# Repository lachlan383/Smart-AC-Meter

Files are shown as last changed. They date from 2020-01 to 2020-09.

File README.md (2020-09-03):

# Smart-AC-Meter
Project repo for the hardware and software design of a household AC power monitor with smartphone interface.

***Update 2020-08-24:***
PCBs arrived a few weeks ago and have now been fully assembled and successfully tested. Soldering of the 0.5mm QFN was extremely tricky and only successful (initially) on one of the three boards. For a full hardware build and verification writeup please see the [Hardware Review Document](https://github.com/lachlan383/Smart-AC-Meter/raw/master/Documentation/Hardware%20Review.docx)*(TBD)*.

<p align="center">
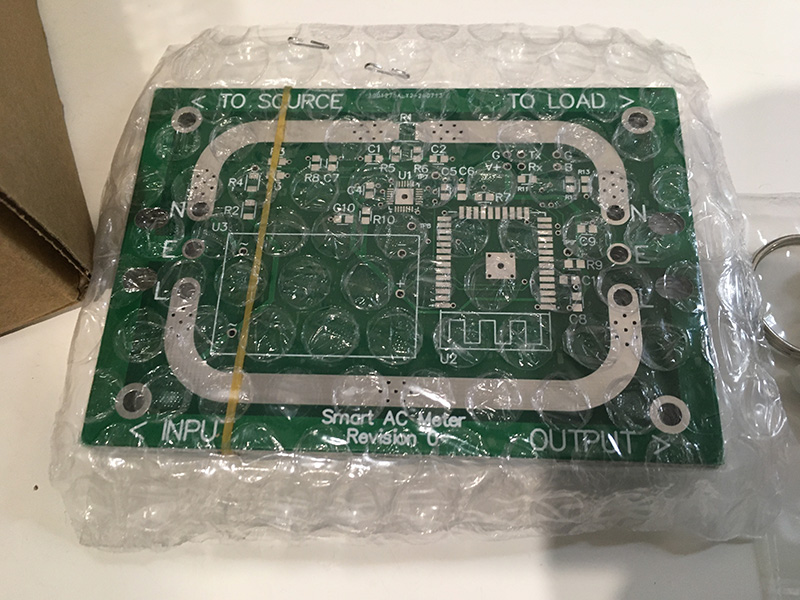
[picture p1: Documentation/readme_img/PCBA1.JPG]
    
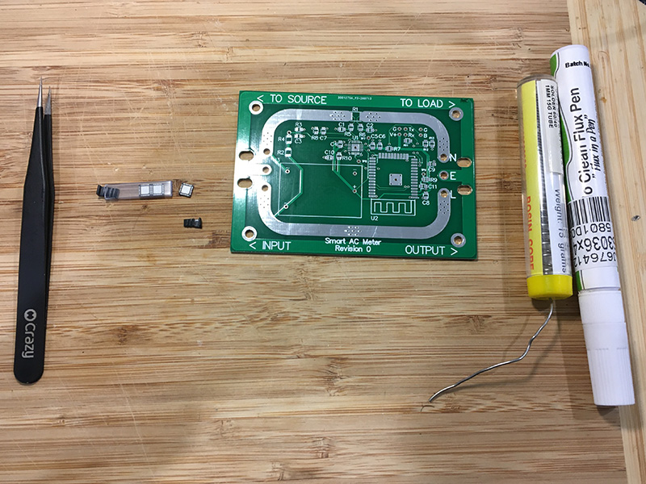
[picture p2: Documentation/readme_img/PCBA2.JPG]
    
  <br/>
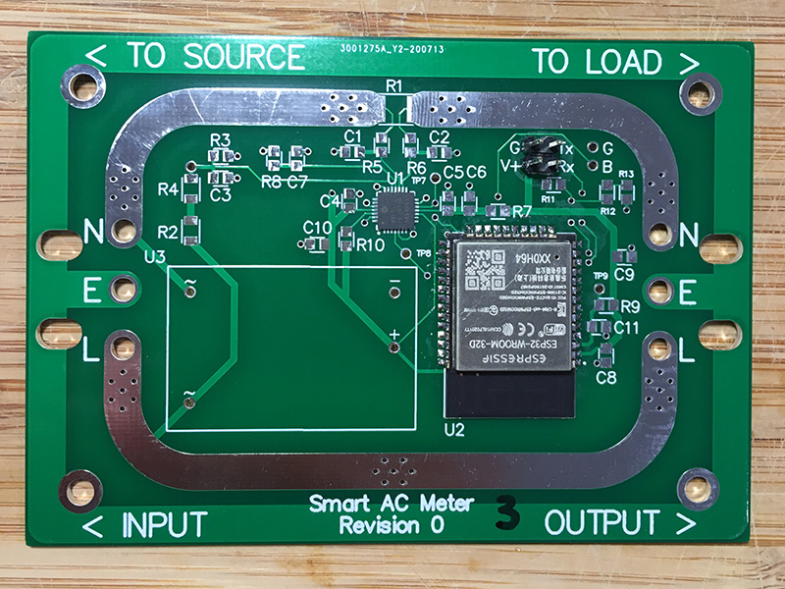
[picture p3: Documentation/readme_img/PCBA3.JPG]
    
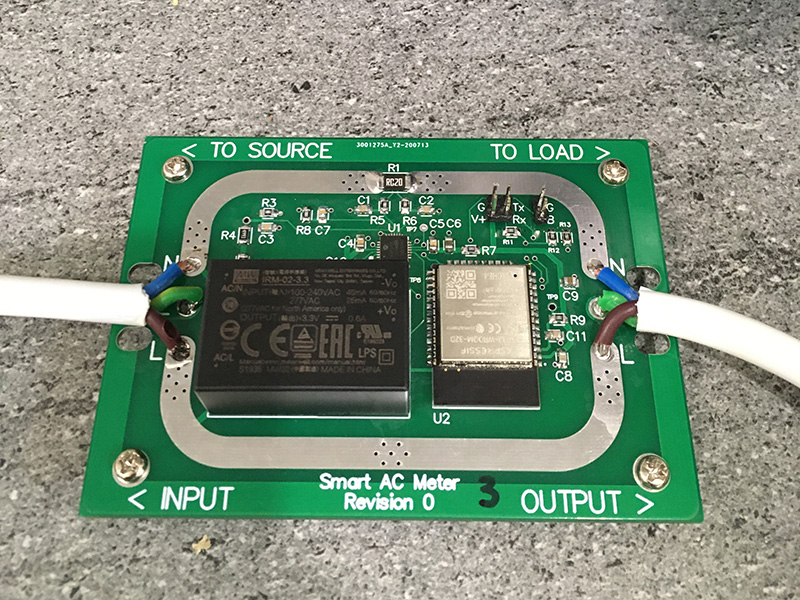
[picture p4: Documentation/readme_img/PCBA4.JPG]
    
  <br/>
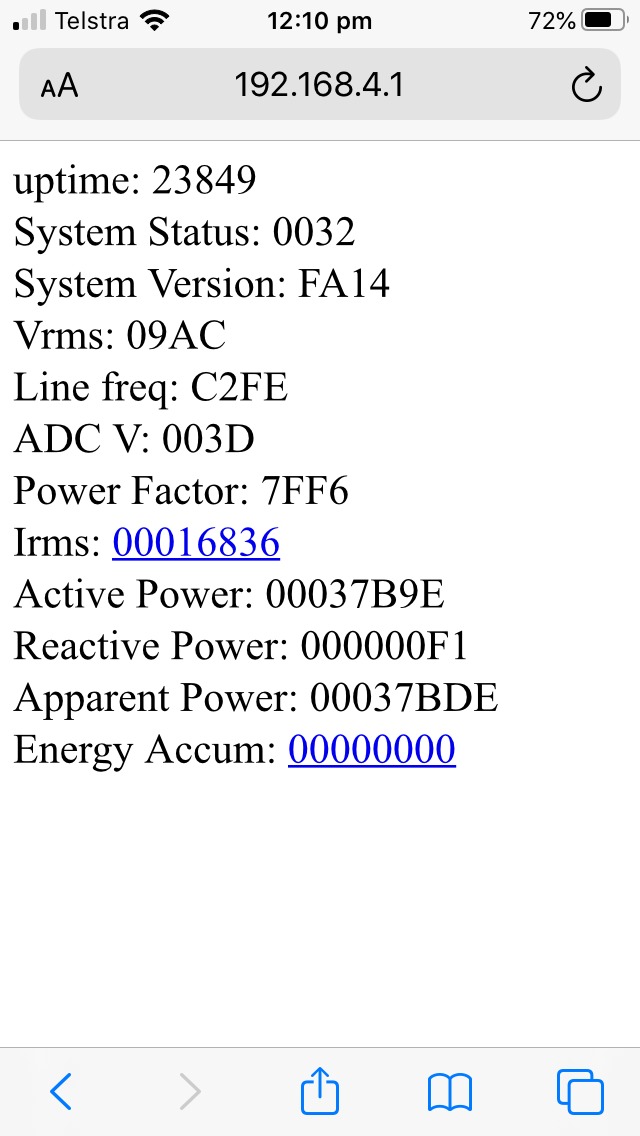
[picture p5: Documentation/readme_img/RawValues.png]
    
          
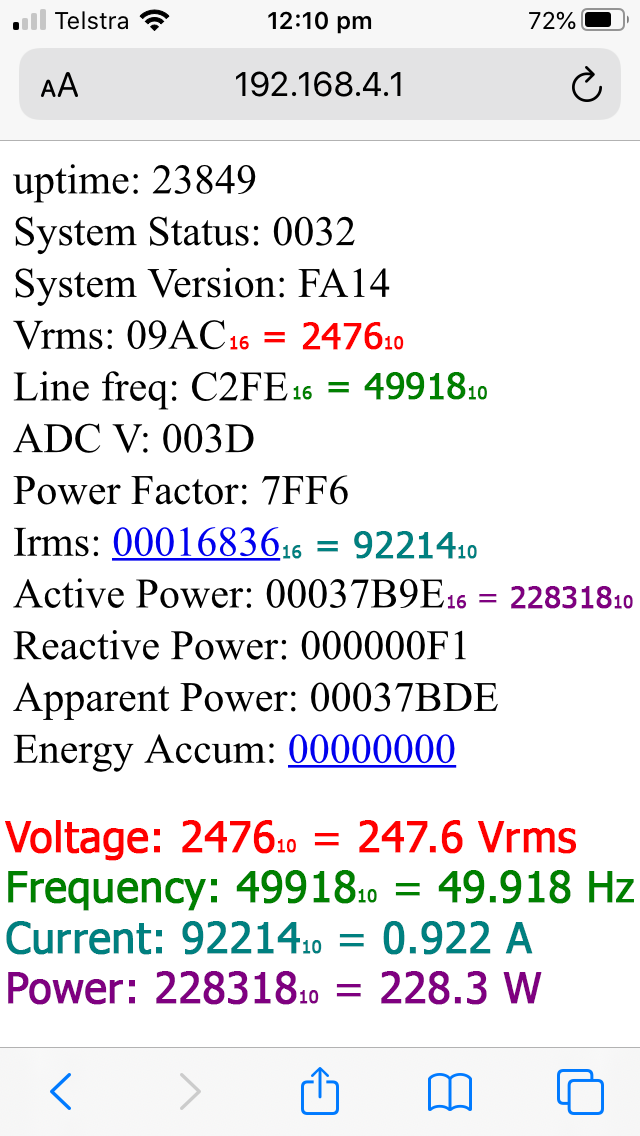
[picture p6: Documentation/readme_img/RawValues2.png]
    
</p>

***Update 2020-07-20:***
BOM and PCBs have been ordered for hand-assembly from Digikey and JLCPCB.com. BOM has now arrived:

<p align="center">
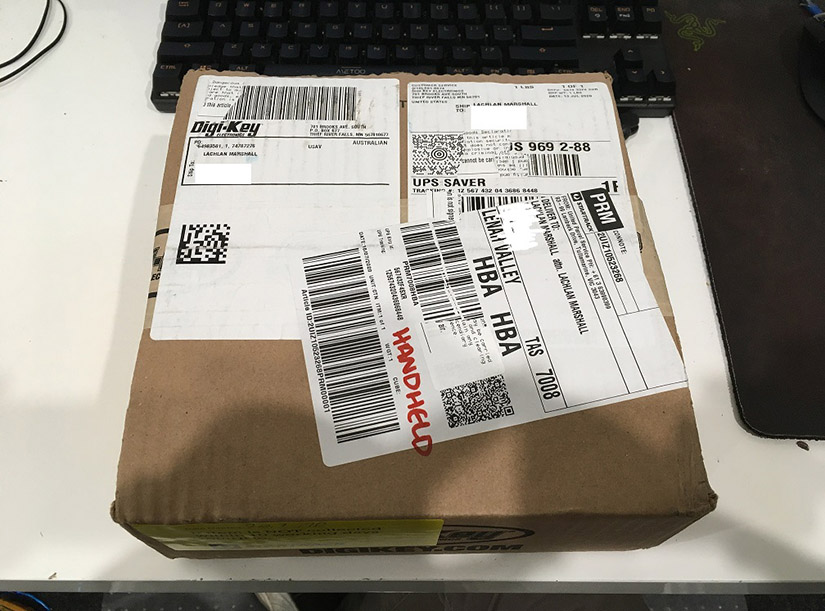
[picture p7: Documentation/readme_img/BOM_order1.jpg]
  
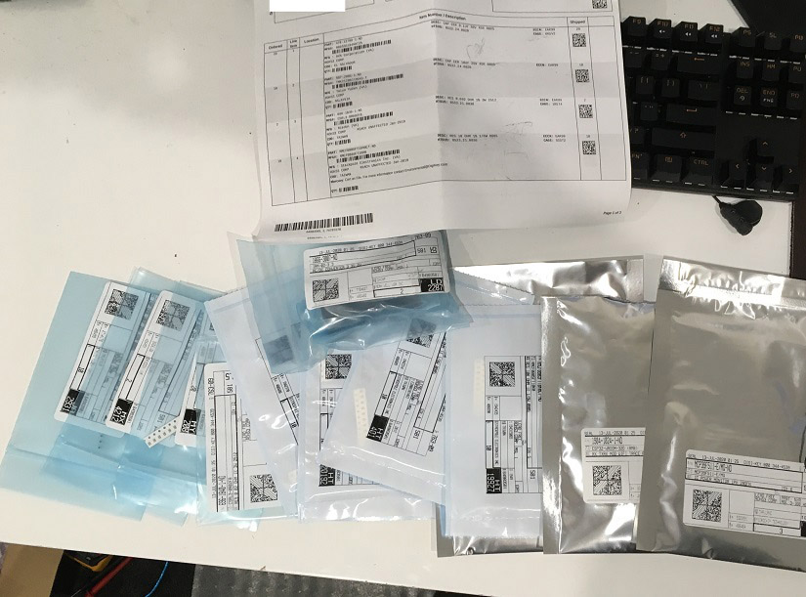
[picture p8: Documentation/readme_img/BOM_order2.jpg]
  
</p>

As soon as the PCBs arrive the boards can be hand-soldered and tested.
  
## *Project Outline*

For an in-depth overview of the initial concept, please read the [Initial Project Outline](https://github.com/lachlan383/Smart-AC-Meter/raw/master/Documentation/Initial%20Project%20Outline.docx):

<p align="center"> 
<a href="https://github.com/lachlan383/Smart-AC-Meter/raw/master/Documentation/Initial%20Project%20Outline.docx">
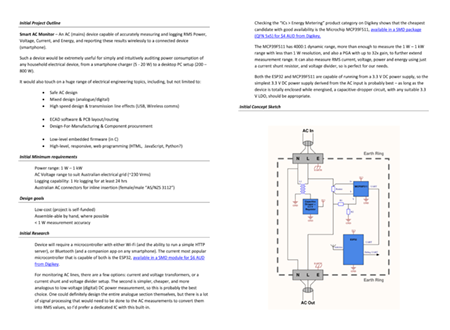
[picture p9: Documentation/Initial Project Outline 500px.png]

</a>
</p>

## *Progress*

Project is currently in the hardware design stage - latest schematic and PCB prints are available at [Altium Project/output/prints.PDF](https://github.com/lachlan383/Smart-AC-Meter/blob/master/Altium%20Project/output/prints.PDF):

<p align="center"> 
<a href="https://github.com/lachlan383/Smart-AC-Meter/blob/master/Altium%20Project/output/prints.PDF">
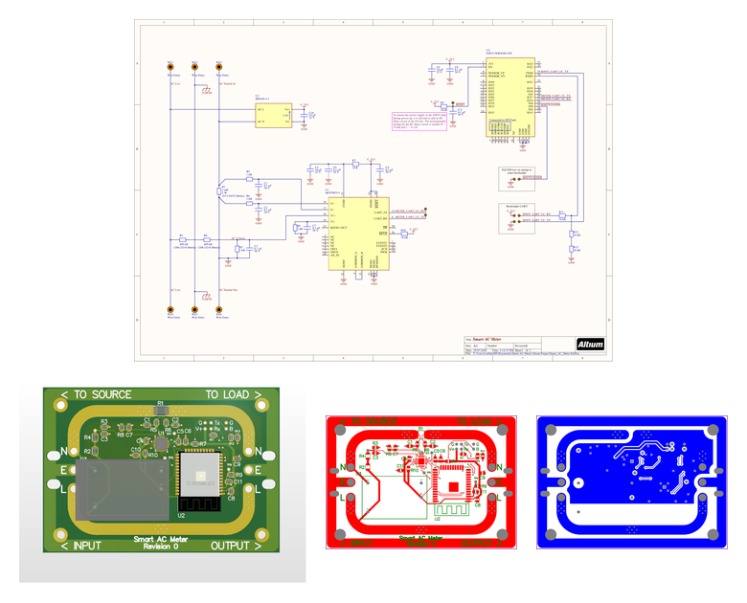
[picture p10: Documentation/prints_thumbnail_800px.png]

</a>
</p>

As the hardware design is nearly completed, I have sent the design files to a trusted peer and asked them to review. This design review, and my replies and changes are contained in the [Design Review.txt](https://github.com/lachlan383/Smart-AC-Meter/raw/master/Documentation/Design%20Review.txt).

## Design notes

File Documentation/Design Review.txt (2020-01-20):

Anonymous review 2020/01/14
===========================

* [Design review comment]

>> [Designer's reply]

* What are the withstanding voltages of your sense/AC side resistors? if the
  output was shorted they would probably survive from a power POV but would
  their dielectric breakdown with 230V across them?

>> The voltage sense resistors are both 1206, with a working voltage of 200 V
   each, giving 400 V working voltage for two in series, more than enough for
   240 V AC ( 240 * sqrt(2) = 340 Vpk ). The 1206 resistors also have a
   withstanding voltage together of 800 V, so even better.
   The current sense resistor cannot fail in such a way as to allow the full
   line voltage across it. Even in the case of a short on the output L and N
   terminals, the over-current condition will trip a fuse or breaker before
   damaging this resistor (note that normal Australian AC outlets are maximally
   15 A) as 15 A * 2 mOhm = 30 mV, and 15 A * 30 mV = 450 mW, well within all
   this resistors ratings (it is a 3 W, 2512 resistor).

* The datasheet vaguely hints at using ferrite beads in series with the 1k
  resistors on the current sense lines and its been implemented on the eval
  board. Probably overkill but might help with some higher frequency filtering
  when measuring a noisy PC?
  
>> These ferrite beads aren't well documented, but the only justification I can
   think of is for conducted EMI protection/prevention - something I am happy
   to forego in an extreme low-cost, one-off prototype device, even though it
   is good practice in general.
   Regarding filtering noisy devices being measured, I'm not sure that we
   actually want to do that - the MCP39F511 measures several factors such as
   real & reactice power, as well as power factor, and filtering out harmonic
   content from a noisy supply could make a device look better/"cleaner" than
   it really is.
   The frequency at which a ferrite bead acts is obviously far above the
   sampling frequency of the MCP39F511's ADCs, though, so maybe the above point
   isn't really relevant.

* Also, the datasheet uses 33nF filtering caps.

>> Well spotted. The 3 dB frequency for 1kOhm//100nF is 1.6 kHz, and a bit
   under 5 kHz for the ferrite bead + 1 kOhm + 33 nF as is done on the eval
   board. For now, I think it should be safe to use the same 100 nF cap as is
   used everywhere else, since the 3 dB frequency is so far from the signal of
   interest (50 Hz vs. 1.6 kHz). But, this capacitor is one of the simplest
   and cheapest things to rework after the fact - it would only take 2 minutes,
   and less than a dollar in cost, to replace all the 100 nF caps with 33 nF
   caps, so maybe that is a good exercise to do when the boards arrive, to see
   what effect it really has.

* I don't know much about the ESP32 so maybe a stupid question but - how do you
  program it?
  
>> The ESP32-WROOM module ships with a bootloader pre-installed that responds
   to programming over the serial port (UART0), when IO0 is pulled low.
   Otherwise, it has JTAG pins broken out as well, which could be soldered to
   directly if required.

* Maybe add some points to access the UART externally?

>> Yep, these will be needed for programming, I wasn't sure of the best way to
   do so, I have added 100 mil spaced vias/holes above the ESP32 that could
   either be soldered directly to, or have male, or female 100 mil spaced
   header pins/sockets attached.

* As this is a logging platform, it might be cool to add the thermistor stuff
  to the analogue input channel so you could also log external temperature?
  (more complication...)
  
>> Definitely would be cool, and pretty easy too - but, in the interest of
   keeping component count, complexity, and cost as low as absolutely possible,
   I am going to opt not to add the temperature circuitry to this first design.

* From your layout it looks as if the mounting holes are connected to Earth? If
  not, I think they should be.
  
>> Indeed they are, although I thought I might use nylon standoffs and an
   enclosure made of perspex or similar, in order to prevent having any exposed
   conductive surfaces whatsoever.

* Give your PCB a name and label it in silkscreen with revision etc (looks more
  professional)
  
>> Done, thanks.

* It may be a bit difficult to get to the components between the PSU and ESP32
  (unlikely to ever need rework).
  
>> The AC/DC power supply (PSU) is the last thing to be soldered, after the
   rest of the design has been completely tested and verified, so hopefully
   this won't be an issue. If it is, the PSU is only connected by four small
   pins so it wouldn't be hard to completely remove it to rework any parts it
   might be obscuring.

* Label the input and output in silkscreen

>> Definitely a good idea, done.

* In fact, get rid of the WE* designator labels and add your own for Live,
  Neutral and Earth

>> Done.

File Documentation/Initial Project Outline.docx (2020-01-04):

Initial Project Outline

Smart AC Monitor – An AC (mains) device capable of accurately measuring and logging RMS Power, Voltage, Current, and Energy, and reporting these results wirelessly to a connected device (smartphone).

Such a device would be extremely useful for simply and intuitively auditing power consumption of any household electrical device, from a smartphone charger (5 - 20 W) to a desktop PC setup (200 – 800 W).

It would also touch on a huge range of electrical engineering topics, including, but not limited to:

- Safe AC design
- Mixed design (analogue/digital)
- High speed design & transmission line effects (USB, Wireless comms)
- ECAD software & PCB layout/routing
- Design-For-Manufacturing & Component procurement
- Low-level embedded firmware (in C)
- High-level, responsive, web programming (HTML, JavaScript, Python?)

Initial Minimum requirements

Power range: 1 W – 1 kW

AC Voltage range to suit Australian electrical grid (~230 Vrms)

Logging capability: 1 Hz logging for at least 24 hrs
Australian AC connectors for inline insertion (female/male “AS/NZS 3112”)

Design goals

Low-cost (project is self-funded)
Assemble-able by hand, where possible
< 1 W measurement accuracy

Initial Research

Device will require a microcontroller with either Wi-Fi (and the ability to run a simple HTTP server), or Bluetooth (and a companion app on any smartphone). The current most popular microcontroller that is capable of both is the ESP32, available in a SMD module for $6 AUD from Digikey (https://www.digikey.com.au/product-detail/en/espressif-systems/ESP32-WROOM-32D/1904-1023-1-ND/9381732).

For monitoring AC lines, there are a few options: current and voltage transformers, or a current shunt and voltage divider setup. The second is simpler, cheaper, and more analogous to low-voltage (digital) DC power measurement, so this is probably the best choice. One could definitely design the entire analogue section themselves, but there is a lot of signal processing that would need to be done to the AC measurements to convert them into RMS values, so I’d prefer a dedicated IC with this built-in.

Checking the “ICs > Energy Metering” product category on Digikey shows that the cheapest candidate with good availability is the Microchip MCP39F511, available in a SMD package (QFN 5x5) for $4 AUD from Digikey. (https://www.digikey.com.au/product-detail/en/microchip-technology/MCP39F511-E-MQ/MCP39F511-E-MQ-ND/5323591)

The MCP39F511 has 4000:1 dynamic range, more than enough to measure the 1 W – 1 kW range with less than 1 W resolution, and also a PGA with up to 32x gain, to further extend measurement range. It can also measure RMS current, voltage, power and energy using just a current shunt resistor, and voltage divider, so is perfect for our needs.

Both the ESP32 and MCP39F511 are capable of running from a 3.3 V DC power supply, so the simplest 3.3 V DC power supply derived from the AC input is probably best – as long as the device is totally enclosed while energised, a capacitive-dropper circuit, with any suitable 3.3 V LDO, should be appropriate.

Initial Concept Sketch

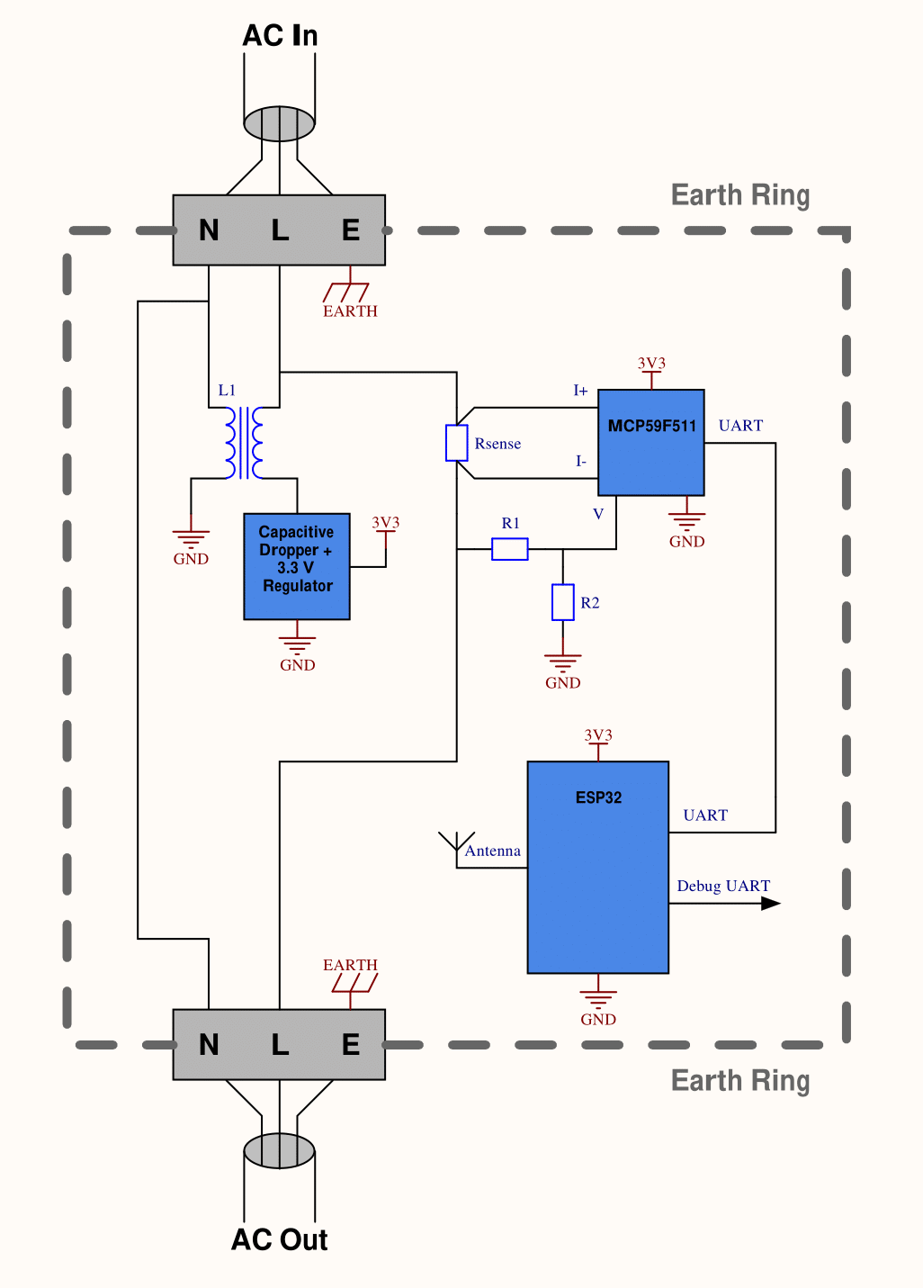
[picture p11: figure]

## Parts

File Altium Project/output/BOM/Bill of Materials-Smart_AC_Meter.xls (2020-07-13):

Description | LibRef | Unique Part Number | Designator | Manufacturer Part Number | Digikey Part Number | Quantity
AVX Corporation 08055D104KAT2A | Capacitor | LM_CAP_0001 | C1, C2, C3, C4, C6, C7, C8, C11 | AVX Corporation 08055D104KAT2A | 478-12790-1-ND | 8.0
 | Taiyo Yuden TMK212BBJ106KG-T | LM_CAP_0002 | C5, C9, C10 | Taiyo Yuden TMK212BBJ106KG-T | 587-2985-1-ND | 3.0
 | 2 mR 2512 (6432 Metric) Chip | LM_RES_0002 | R1 | Riedon CSRL3-0R002F8 | 696-1836-1-ND | 1.0
 | 499 kR 1206 (3216 Metric) Chip | LM_RES_0003 | R2, R4 | Stackpole Electronics Inc RMCF1206FT499K | RMCF1206FT499KCT-ND | 2.0
 | 1 kR 0805 (2012 Metric) Chip | LM_RES_0001 | R3, R5, R6, R8 | Stackpole Electronics Inc RMCF0805FT1K00 | RMCF0805FT1K00CT-ND | 4.0
 | 10 R 0805 (2012 Metric) Chip | LM_RES_0004 | R7 | Stackpole Electronics Inc RMCF0805FT10R0 | RMCF0805FT10R0CT-ND | 1.0
 | 10 kR 0805 (2012 Metric) Chip | LM_RES_0005 | R9, R10, R11, R12, R13 | Stackpole Electronics Inc RMCF0805FT10K0 | RMCF0805FT10K0CT-ND | 5.0
1mm dia via/through hole | Via | LM_OTH_0002 | TP1, TP2, TP3, TP4, TP5, TP6, TP7, TP8, TP9 |  |  | 9.0
Single Phase Meter IC 28-QFN (5x5) | MCP39F511 | LM_IC_0001 | U1 | Microchip Technology MCP39F511-E/MQ | MCP39F511-E/MQ-ND | 1.0
Bluetooth, WiFi,3 Transceiver Module | ESP32-WROOM-32D | LM_IC_0002 | U2 | Espressif Systems ESP32-WROOM-32D | 1904-1023-1-ND | 1.0
Enclosed AC DC Converter 1 Output 3.3V 600mA | IRM-02-3.3 | LM_IC_0003 | U3 | MEAN WELL USA Inc. IRM-02-3.3 | 1866-3007-ND | 1.0
12 AWG Wire Entry | Wire Entry | LM_OTH_0001 | WE1, WE2, WE3, WE4, WE5, WE6 |  |  | 6.0

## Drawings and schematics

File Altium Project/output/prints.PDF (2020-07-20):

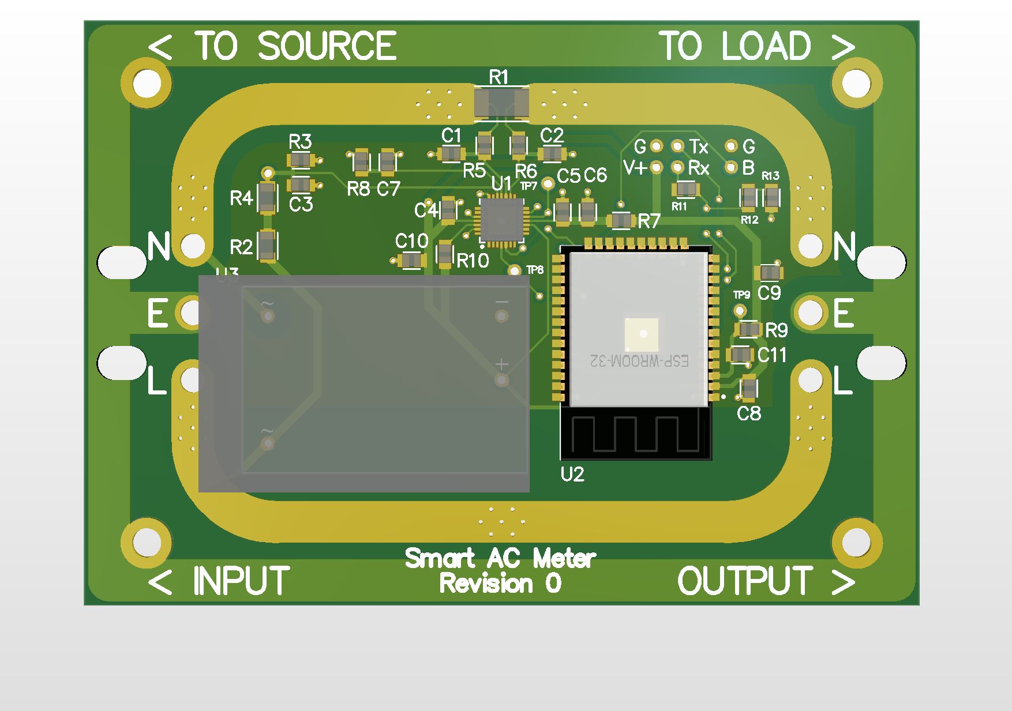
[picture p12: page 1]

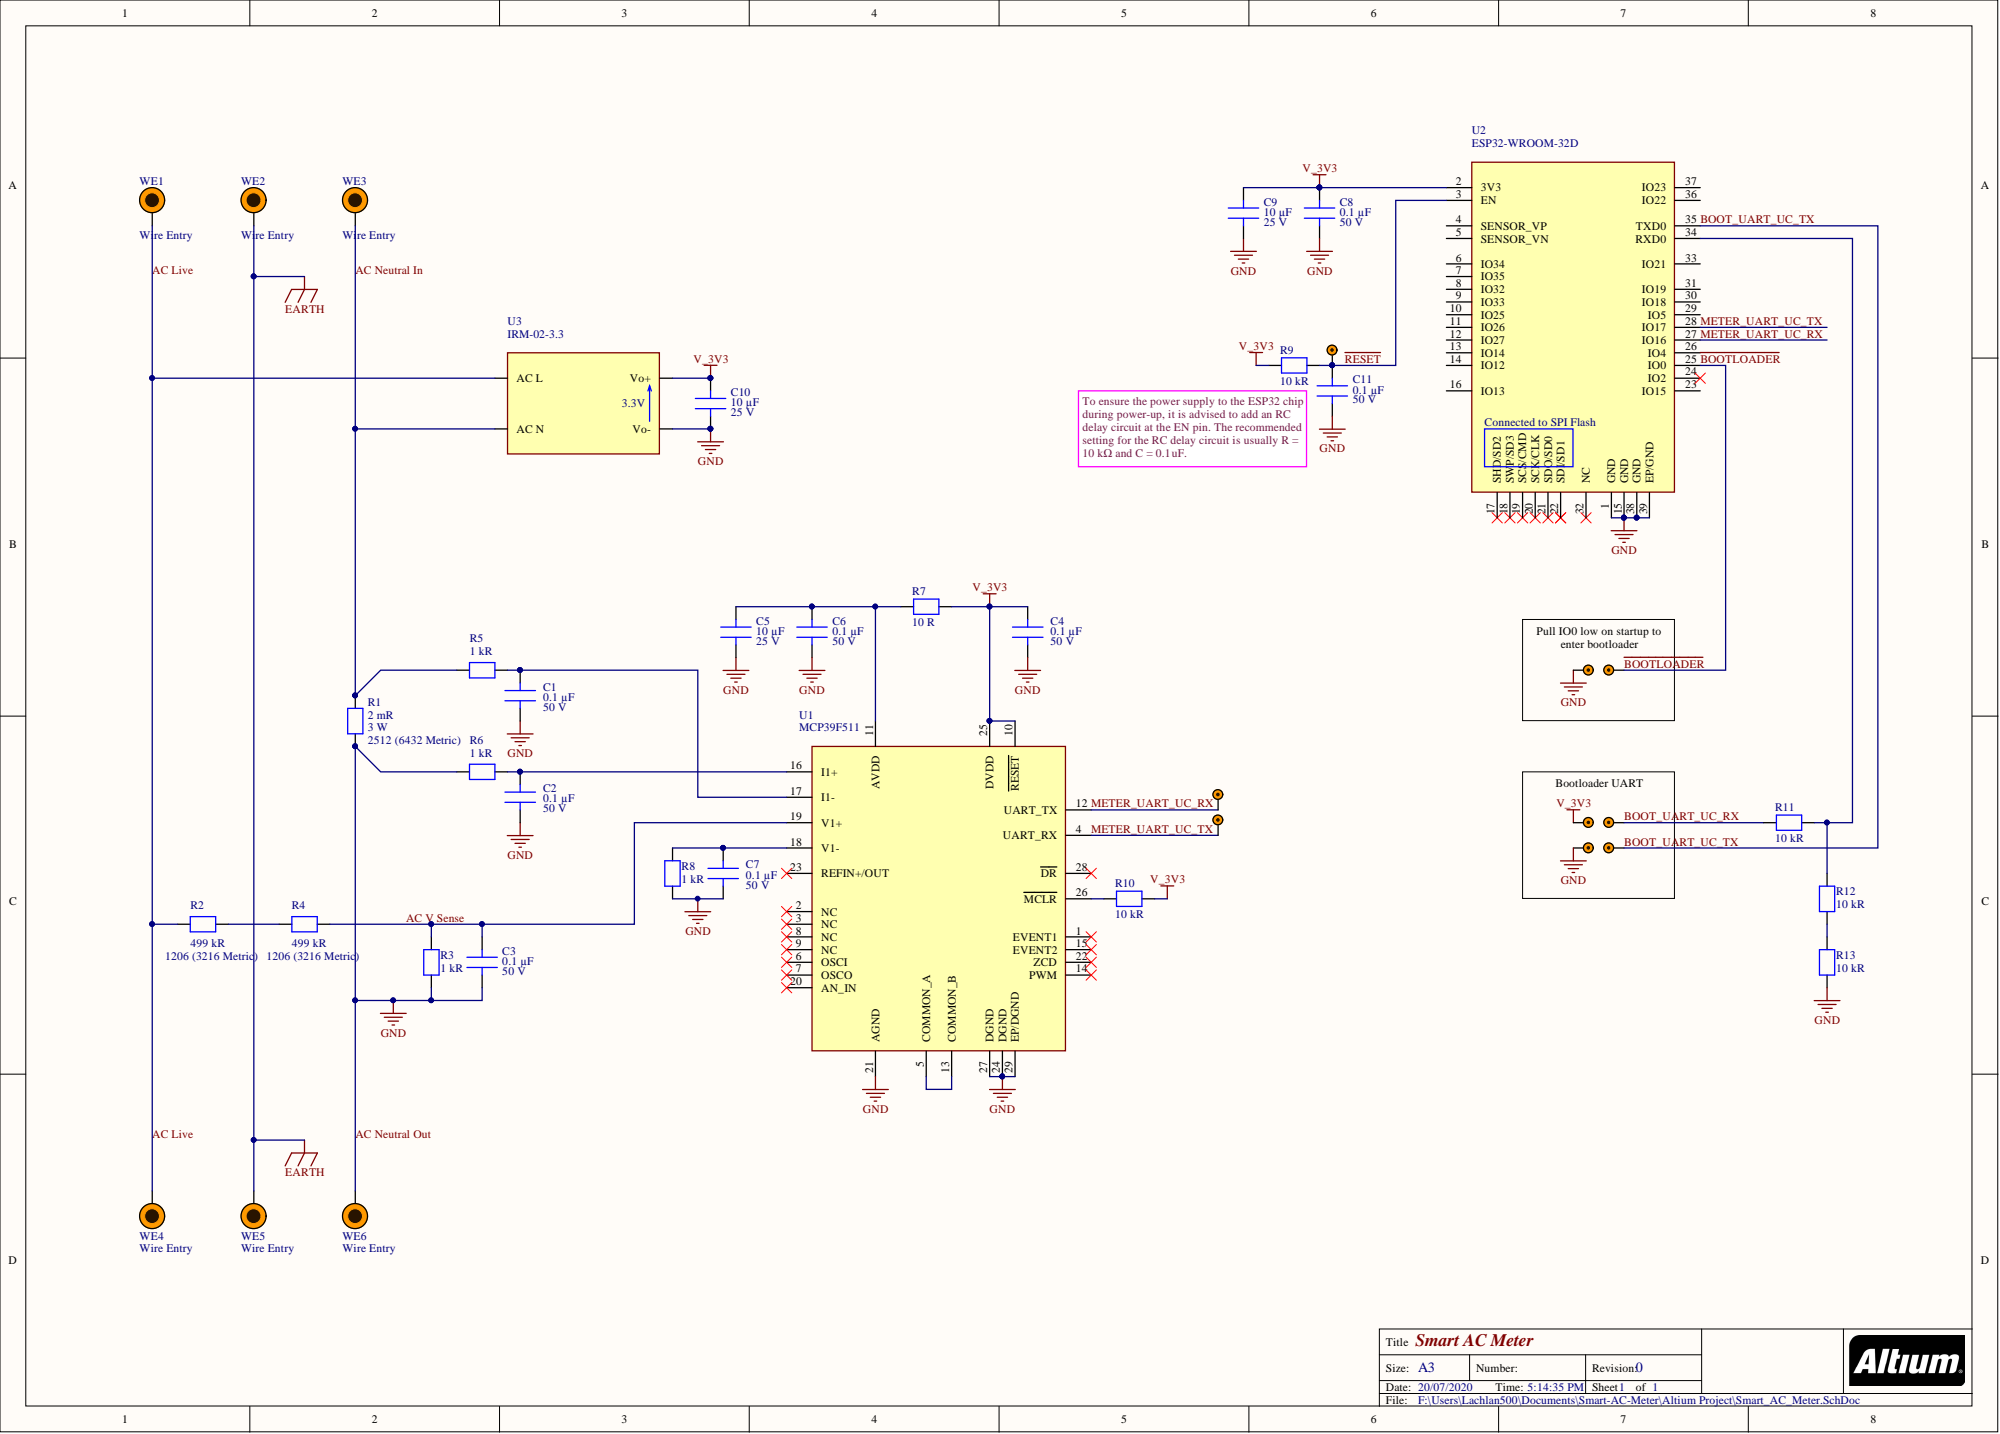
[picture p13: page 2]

To ensure the power supply to the ESP32 chip
during power-up, it is advised to add an RC
delay circuit at the EN pin. The recommended
setting for the RC delay circuit is usually R =
10 kΩ and C = 0.1 uF.

Connected to SPI Flash

Pull IO0 low on startup to
enter bootloader

Title Smart AC Meter

Size: A3 | Number: | Revision: 0
Date: 20/07/2020 Time: 5:14:35 PM | | Sheet 1 of 1

F:\Users\Lachlan500\Documents\Smart-AC-Meter\Altium Project\Smart_AC_Meter.SchDoc

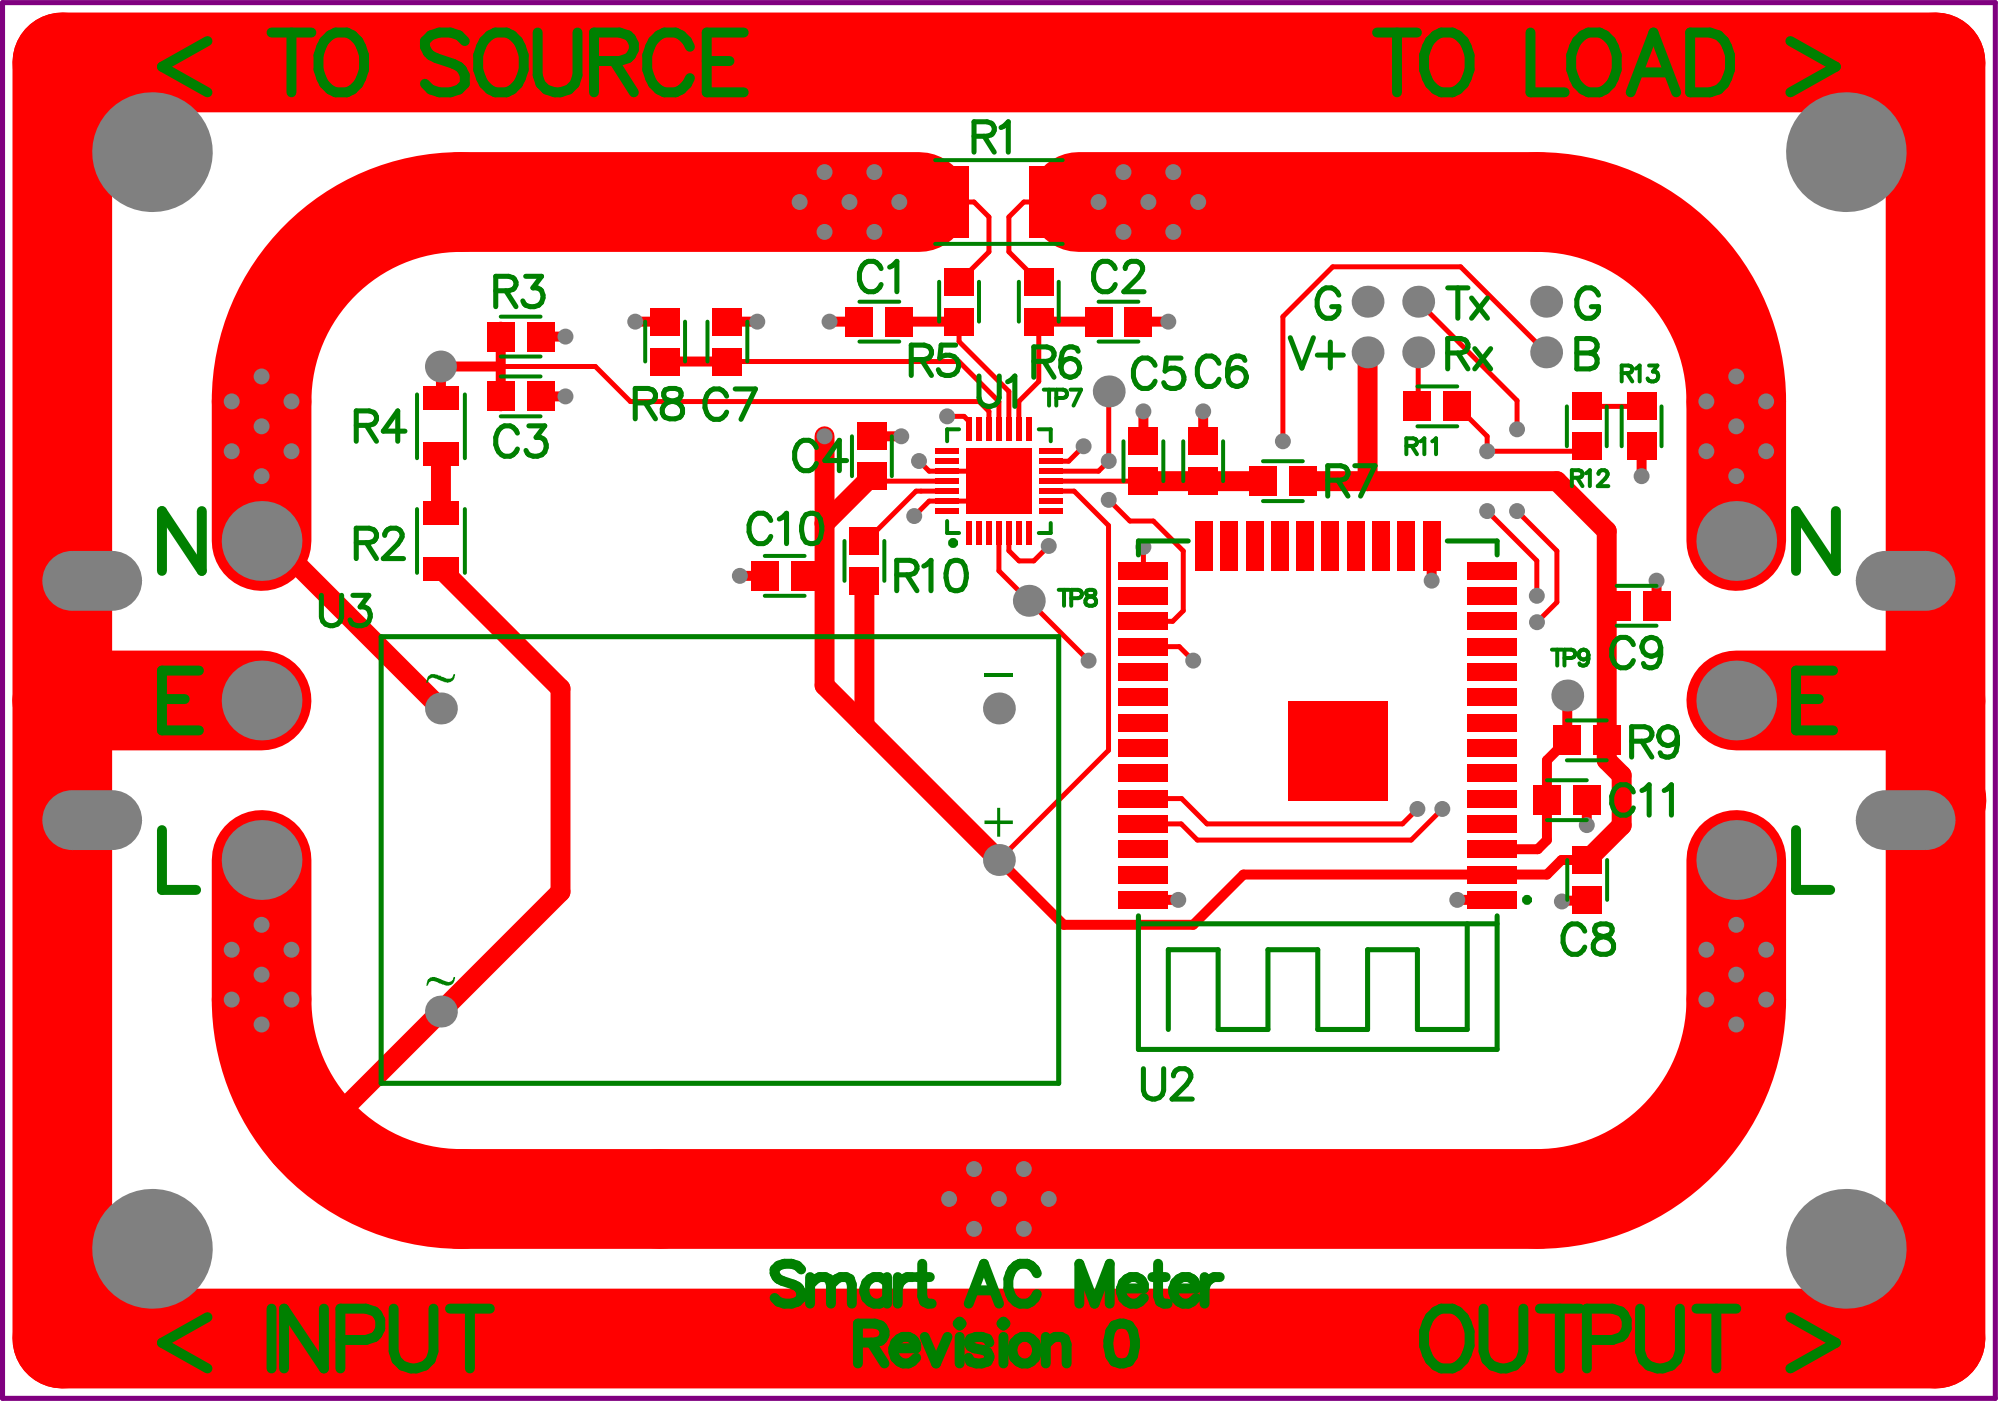
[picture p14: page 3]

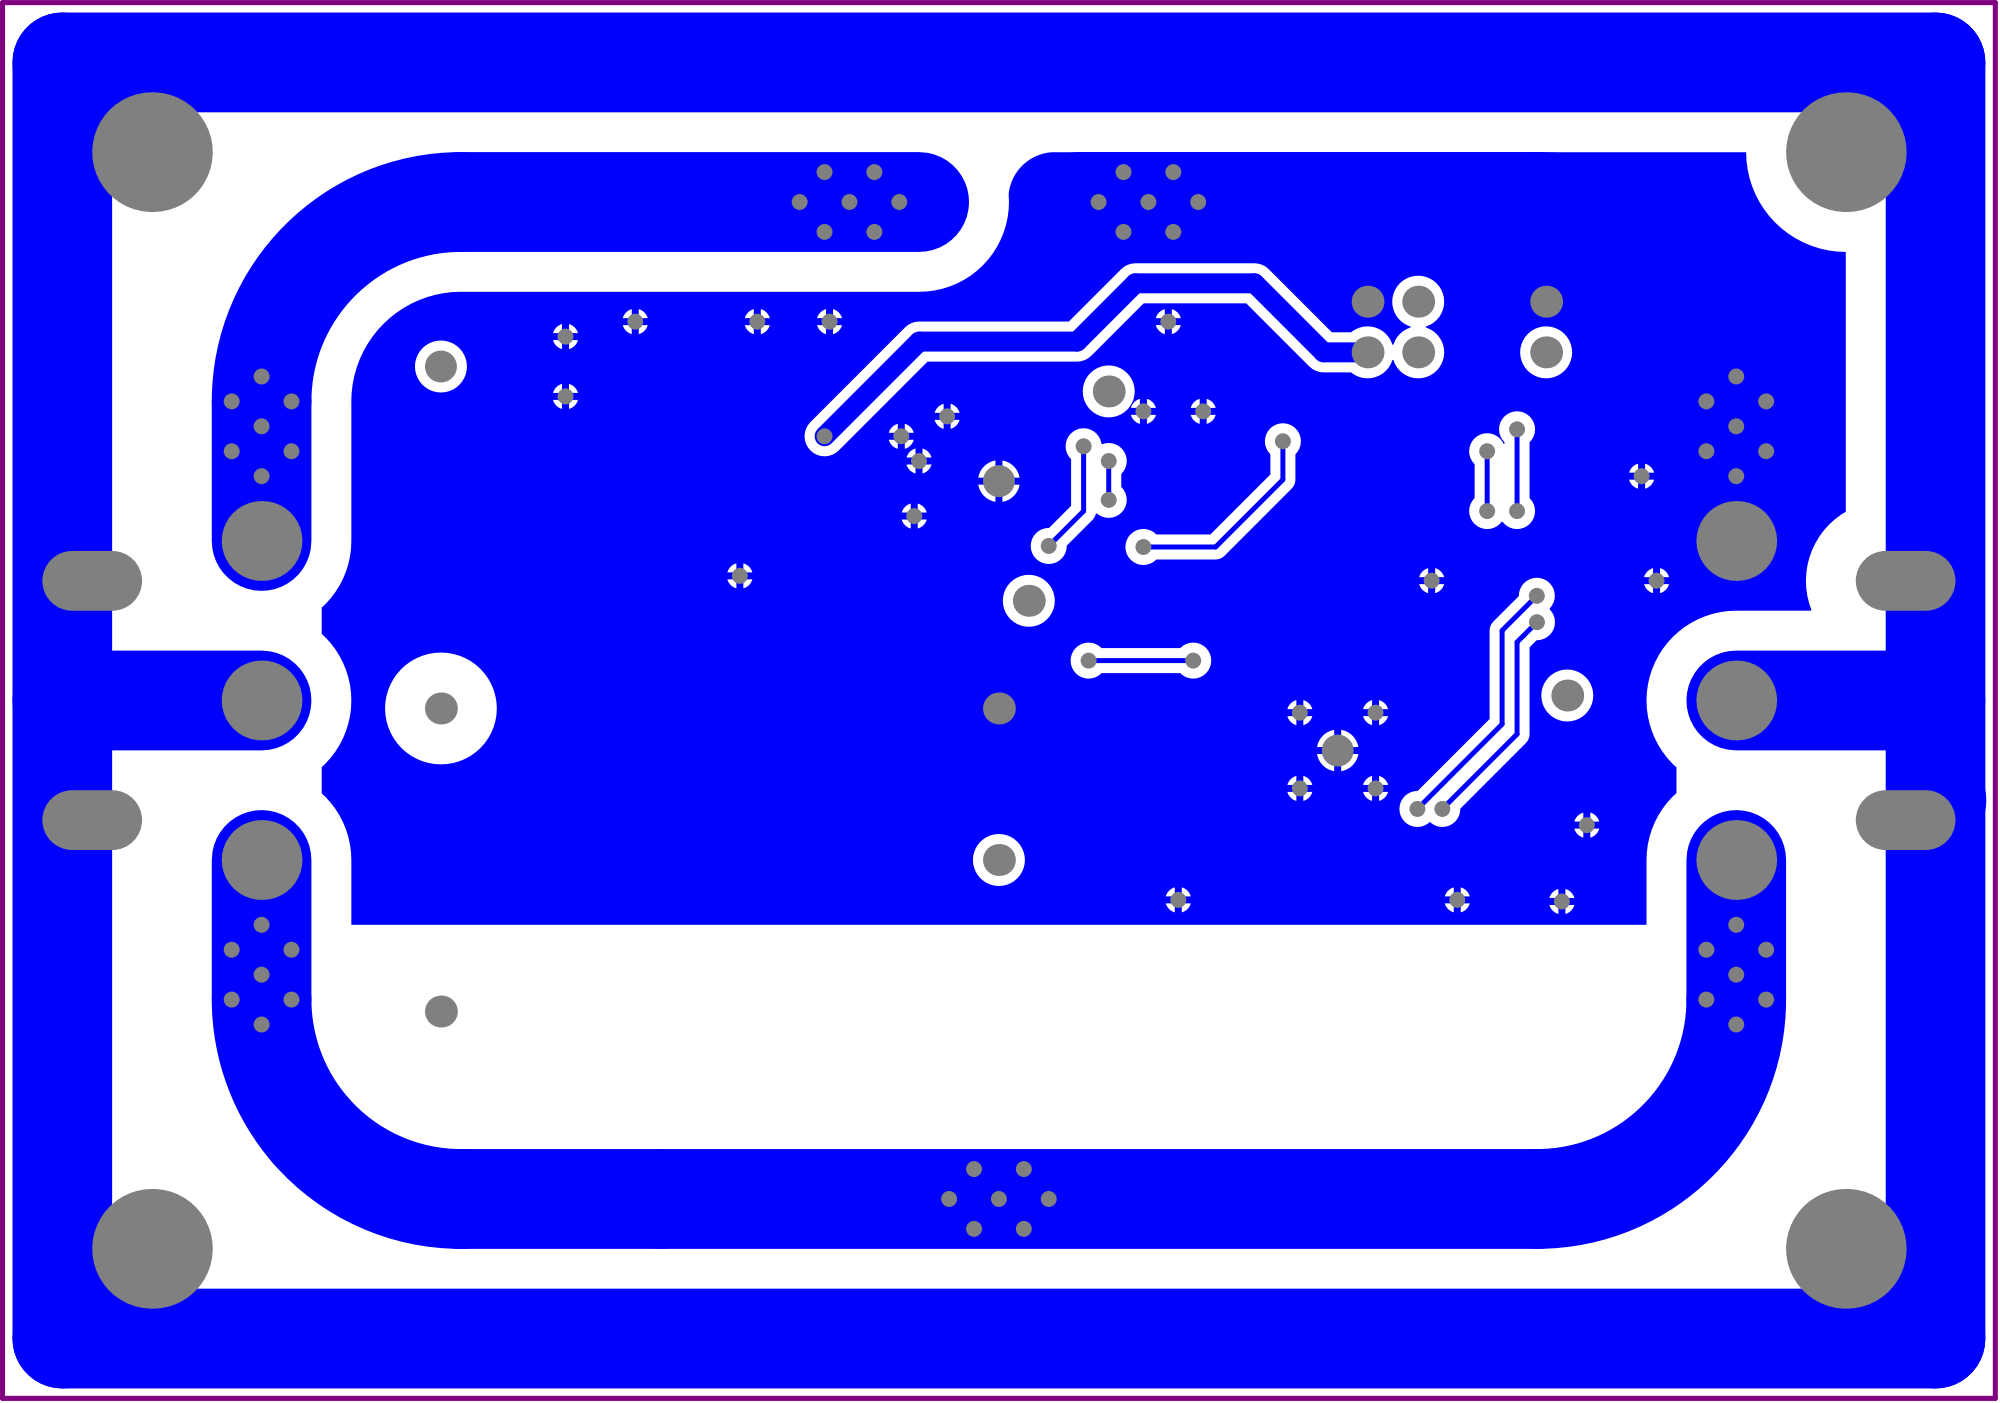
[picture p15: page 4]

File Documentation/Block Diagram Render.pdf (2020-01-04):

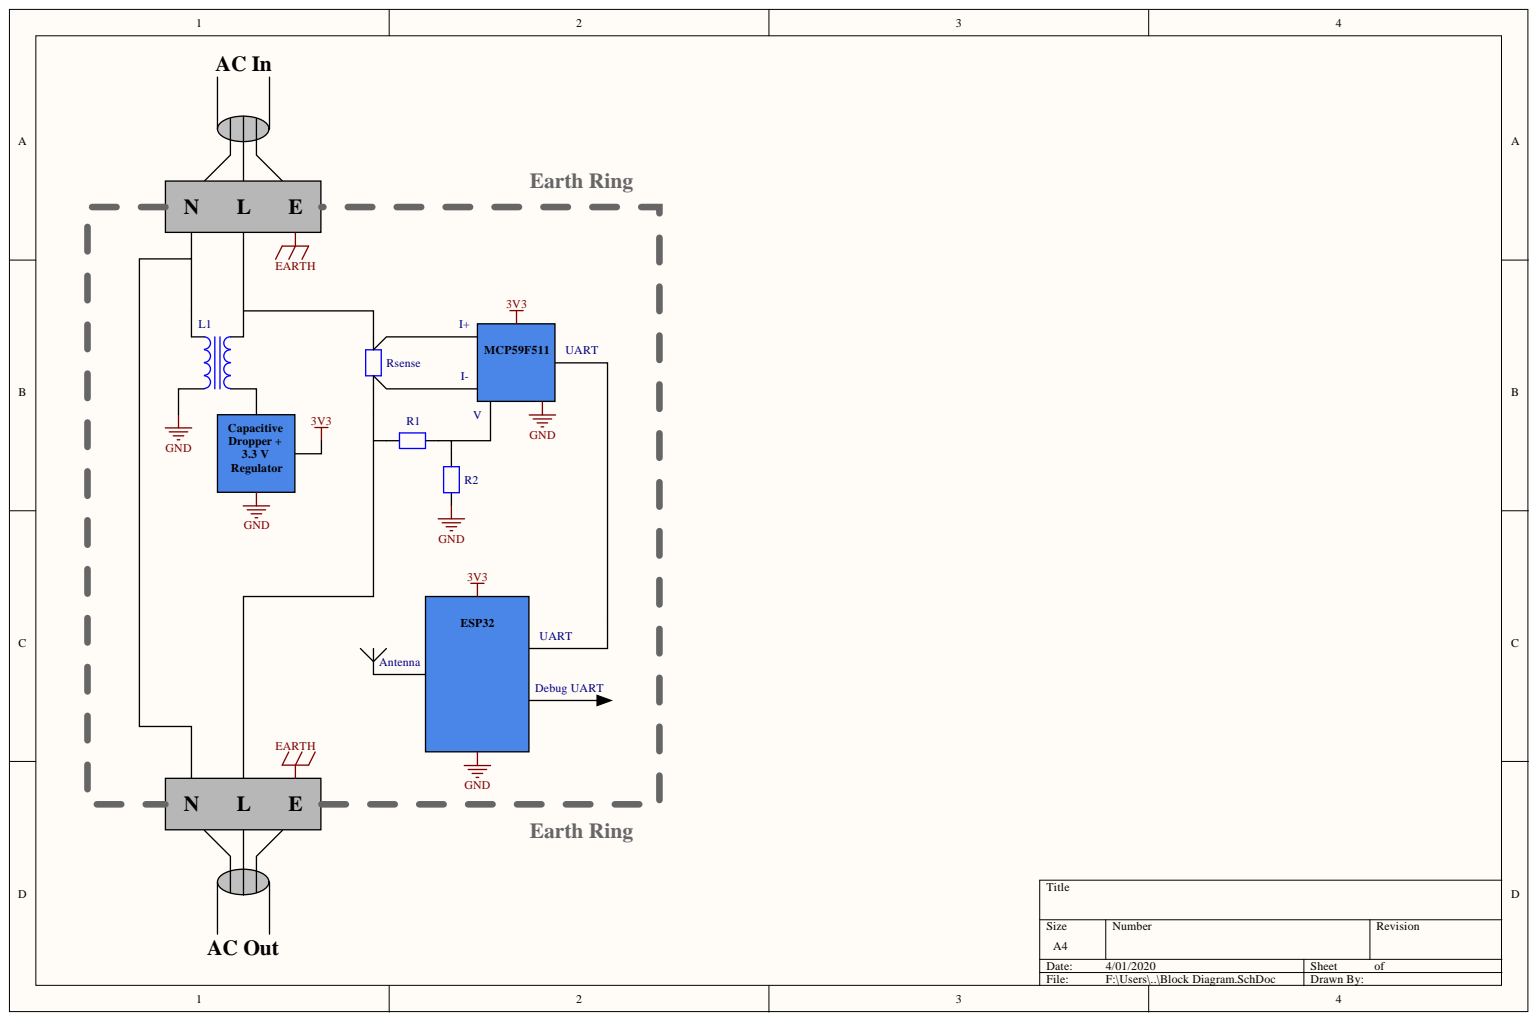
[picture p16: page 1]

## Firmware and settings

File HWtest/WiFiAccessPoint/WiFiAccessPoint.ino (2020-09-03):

/*
  WiFiAccessPoint.ino creates a WiFi access point and provides a web server on
  it.

  Steps:
  1. Connect to the access point "ESP32_Power"
  2. Point your web browser to http://192.168.4.1/
*/

#include <WiFi.h>
#include <WiFiClient.h>
#include <WiFiAP.h>

#define RXD2 16
#define TXD2 17
char msg[] = {0xA5, 0x08, 0x41, 0x00, 0x02, 0x4E, 0x20};
char chksum;
char hex[] = {'0', '1', '2', '3', '4', '5', '6', '7', '8', '9', 'A', 'B', 'C',
  'D', 'E', 'F'};

// Set these to your desired credentials.
const char *ssid = "ESP32_Power";
const char *password = "lachie383";

WiFiServer server(80);
WiFiClient client;

void serialHexByte(char b){
  client.print(hex[b>>4]);
  client.print(hex[b&0x0F]);
}

void serialHexShort(uint16_t b){
  serialHexByte(b>>8);
  serialHexByte(b&0xFF);
}

void serialHexInt(uint32_t b){
  serialHexShort(b>>16);
  serialHexShort(b&0xFFFF);
}

void setup() {

  Serial.begin(115200);
  Serial2.begin(115200, SERIAL_8N1, 16, 17);
  Serial.println();
  Serial.println("Configuring access point...");

  // You can remove the password parameter if you want the AP to be open.
  WiFi.softAP(ssid, password);
  IPAddress myIP = WiFi.softAPIP();
  Serial.print("AP IP address: ");
  Serial.println(myIP);
  server.begin();

  Serial.println("Server started");
}

void loop() {
  client = server.available();   // listen for incoming clients

  if (client) {                             // if you get a client,
    Serial.println("New Client.");           // print a message out the serial port
    
    String currentLine = "";                // make a String to hold incoming data from the client
    while (client.connected()) {            // loop while the client's connected
      if (client.available()) {             // if there's bytes to read from the client,
        char c = client.read();             // read a byte, then
        Serial.write(c);                    // print it out the serial monitor
        if (c == '\n') {                    // if the byte is a newline character

          // if the current line is blank, you got two newline characters in a row.
          // that's the end of the client HTTP request, so send a response:
          if (currentLine.length() == 0) {
            // HTTP headers always start with a response code (e.g. HTTP/1.1 200 OK)
            // and a content-type so the client knows what's coming, then a blank line:
            client.println("HTTP/1.1 200 OK");
            client.println("Content-type:text/html");
            client.println();

            chksum = 0;
            for (int i = 0; i < sizeof(msg); i++){
              Serial2.print((char)msg[i]);
              chksum += (char)msg[i];
            }
            Serial2.print((char)chksum);
        
            if (!Serial2.available()){
              delay(10);
            }

            client.print("\nuptime: ");
            client.print(millis());
            client.print("<br>");
        
            uint32_t tmp;
            if (Serial2.read() == 0x06){
              
              Serial2.read(); // num bytes
              
              tmp = Serial2.read();
              tmp += ( Serial2.read() )<<8;
              client.print("System Status: ");
              serialHexShort(tmp);
              client.print("<br>");
              
              tmp = Serial2.read();
              tmp += ( Serial2.read() )<<8;
              client.print("System Version: ");
              serialHexShort(tmp);
              client.print("<br>");
        
              tmp = Serial2.read();
              tmp += ( Serial2.read() )<<8;
              client.print("Vrms: ");
              serialHexShort(tmp);
              client.print("<br>");
        
              tmp = Serial2.read();
              tmp += ( Serial2.read() )<<8;
              client.print("Line freq: ");
              serialHexShort(tmp);
              client.print("<br>");
        
              tmp = Serial2.read();
              tmp += ( Serial2.read() )<<8;
              client.print("ADC V: ");
              serialHexShort(tmp);
              client.print("<br>");
        
              tmp = Serial2.read();
              tmp += ( Serial2.read() )<<8;
              client.print("Power Factor: ");
              serialHexShort(tmp);
              client.print("<br>");
        
              tmp = Serial2.read();
              tmp += ( Serial2.read() )<<8;
              tmp += ( Serial2.read() )<<16;
              tmp += ( Serial2.read() )<<24;
              client.print("Irms: ");
              serialHexInt(tmp);
              client.print("<br>");
        
              tmp = Serial2.read();
              tmp += ( Serial2.read() )<<8;
              tmp += ( Serial2.read() )<<16;
              tmp += ( Serial2.read() )<<24;
              client.print("Active Power: ");
              serialHexInt(tmp);
              client.print("<br>");
        
              tmp = Serial2.read();
              tmp += ( Serial2.read() )<<8;
              tmp += ( Serial2.read() )<<16;
              tmp += ( Serial2.read() )<<24;
              client.print("Reactive Power: ");
              serialHexInt(tmp);
              client.print("<br>");
        
              tmp = Serial2.read();
              tmp += ( Serial2.read() )<<8;
              tmp += ( Serial2.read() )<<16;
              tmp += ( Serial2.read() )<<24;
              client.print("Apparent Power: ");
              serialHexInt(tmp);
              client.print("<br>");
        
              tmp = Serial2.read();
              tmp += ( Serial2.read() )<<8;
              tmp += ( Serial2.read() )<<16;
              tmp += ( Serial2.read() )<<24;
              client.print("Energy Accum: ");
              serialHexInt(tmp);
              client.print("<br>");
        
              Serial2.read(); // chksum
            }

            // The HTTP response ends with another blank line:
            client.println();
            // break out of the while loop:
            break;
          } else {    // if you got a newline, then clear currentLine:
            currentLine = "";
          }
        } else if (c != '\r') {  // if you got anything else but a carriage return character,
          currentLine += c;      // add it to the end of the currentLine
        }
      }
    }
    // close the connection:
    client.stop();
    Serial.println("Client Disconnected.");
  }
}

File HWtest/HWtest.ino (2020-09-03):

#define RXD2 16
#define TXD2 17
char msg[] = {0xA5, 0x08, 0x41, 0x00, 0x02, 0x4E, 0x20};
char chksum;
char hex[] = {'0', '1', '2', '3', '4', '5', '6', '7', '8', '9', 'A', 'B', 'C', 'D', 'E', 'F'};

void serialHexByte(char b){
  Serial.write(hex[b>>4]);
  Serial.write(hex[b&0x0F]);
}

void serialHexShort(uint16_t b){
  serialHexByte(b>>8);
  serialHexByte(b&0xFF);
}

void serialHexInt(uint32_t b){
  serialHexShort(b>>16);
  serialHexShort(b&0xFFFF);
}

void setup() {
  Serial.begin(115200);
  Serial.println("Startup...");
  Serial2.begin(115200, SERIAL_8N1, 16, 17);
}

void loop() {

  chksum = 0;
  for (int i = 0; i < sizeof(msg); i++){
    Serial2.print((char)msg[i]);
    chksum += (char)msg[i];
  }
  Serial2.print((char)chksum);

  if (!Serial2.available()){
    delay(10);
  }

  Serial.print("\nuptime: ");
  Serial.println(millis());

  while (Serial2.available()){
    uint32_t tmp;
    if (Serial2.read() == 0x06){
      
      Serial2.read(); // num bytes
      
      tmp = Serial2.read();
      tmp += ( Serial2.read() )<<8;
      Serial.write("System Status: ");
      serialHexShort(tmp);
      Serial.write('\n');
      
      tmp = Serial2.read();
      tmp += ( Serial2.read() )<<8;
      Serial.write("System Version: ");
      serialHexShort(tmp);
      Serial.write('\n');

      tmp = Serial2.read();
      tmp += ( Serial2.read() )<<8;
      Serial.write("Vrms: ");
      serialHexShort(tmp);
      Serial.write('\n');

      tmp = Serial2.read();
      tmp += ( Serial2.read() )<<8;
      Serial.write("Line freq: ");
      serialHexShort(tmp);
      Serial.write('\n');

      tmp = Serial2.read();
      tmp += ( Serial2.read() )<<8;
      Serial.write("ADC V: ");
      serialHexShort(tmp);
      Serial.write('\n');

      tmp = Serial2.read();
      tmp += ( Serial2.read() )<<8;
      Serial.write("Power Factor: ");
      serialHexShort(tmp);
      Serial.write('\n');

      tmp = Serial2.read();
      tmp += ( Serial2.read() )<<8;
      tmp += ( Serial2.read() )<<16;
      tmp += ( Serial2.read() )<<24;
      Serial.write("Irms: ");
      serialHexInt(tmp);
      Serial.write('\n');

      tmp = Serial2.read();
      tmp += ( Serial2.read() )<<8;
      tmp += ( Serial2.read() )<<16;
      tmp += ( Serial2.read() )<<24;
      Serial.write("Active Power: ");
      serialHexInt(tmp);
      Serial.write('\n');

      tmp = Serial2.read();
      tmp += ( Serial2.read() )<<8;
      tmp += ( Serial2.read() )<<16;
      tmp += ( Serial2.read() )<<24;
      Serial.write("Reactive Power: ");
      serialHexInt(tmp);
      Serial.write('\n');

      tmp = Serial2.read();
      tmp += ( Serial2.read() )<<8;
      tmp += ( Serial2.read() )<<16;
      tmp += ( Serial2.read() )<<24;
      Serial.write("Apparent Power: ");
      serialHexInt(tmp);
      Serial.write('\n');

      tmp = Serial2.read();
      tmp += ( Serial2.read() )<<8;
      tmp += ( Serial2.read() )<<16;
      tmp += ( Serial2.read() )<<24;
      Serial.write("Energy Accum: ");
      serialHexInt(tmp);
      Serial.write('\n');

      Serial2.read(); // chksum
    }
  }

  delay(3000);
}

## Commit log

2020-01-04 LM: First commit of new smart AC monitor sw/hw project
    [Block Diagram.SchDoc, Smart_AC_Monitor.PrjPcb, Smart_AC_Monitor.SchDoc]
2020-01-04 LM: First few components, some PCB brainstorming, first output prints (need to resize pages somehow)
    [Smart_AC_Monitor.PcbDoc, Smart_AC_Monitor.PrjPcb, Smart_AC_Monitor.SchDoc]
2020-01-04 LM: Add note about prints to readme
2020-01-06 LM: Add proper resistors, 3d render, power IC
    [Smart_AC_Monitor.PcbDoc, Smart_AC_Monitor.PrjPcb, Smart_AC_Monitor.SchDoc]
2020-01-06 LM: Add two major ICs, reshuffle L<->N as per MCP39F511A
    [Smart_AC_Monitor.PcbDoc, Smart_AC_Monitor.PrjPcb, Smart_AC_Monitor.SchDoc]
2020-01-06 LM: Add thumbnail preview of prints pdf (and python script to generate the thumbnail)
2020-01-06 LM: Add prints pdf thumbnail preview to readme
2020-01-06 LM: Add decoupling, I/O connections to schematic & PCB
    [Smart_AC_Monitor.PcbDoc, Smart_AC_Monitor.SchDoc]
2020-01-08 LM: Replace cap. dropper with AC/DC module, rename proj files, re-size and re-route PCB
    [Smart_AC_Meter.PcbDoc, Smart_AC_Meter.PrjPcb, Smart_AC_Meter.SchDoc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]
2020-01-08 LM: Fix AC/DC ftpt!
    [Smart_AC_Meter.PcbDoc, Smart_AC_Meter.SchDoc]
2020-01-08 LM: Minor passive placement change
    [Smart_AC_Meter.PcbDoc]
2020-01-10 LM: update all placeholder passives to correct part with MPN
    [Smart_AC_Meter.PcbDoc, Smart_AC_Meter.SchDoc]
2020-01-15 LM: Change ESP32 layout, remove copper under antenna, expose programming connections, add detail to silkscreen
    [Smart_AC_Meter.PcbDoc, Smart_AC_Meter.SchDoc]
2020-01-20 LM: Add design review and design review changes
    [Smart_AC_Meter.PcbDoc]
2020-04-11 LM: Design pack ready for prototype production
    [Bill of Materials-Smart_AC_Meter.xls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]
2020-07-13 LM: touch up ready for board manufacture
    [Bill of Materials-Smart_AC_Meter.xls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]
2020-07-20 LM: no changes to PCBA project, add Digikey order photos
    [Smart_AC_Meter.PcbDoc, Smart_AC_Meter.PrjPcb, Smart_AC_Meter.SchDoc]
2020-07-20 LM: Fix prints pdf highlighting, semi-transparent 3d bodies
    [Smart_AC_Meter.PcbDoc]
